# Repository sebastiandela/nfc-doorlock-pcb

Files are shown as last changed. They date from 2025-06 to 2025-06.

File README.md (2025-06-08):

# NFC-Controlled Electromagnetic Door Lock (Custom PCB)

The design files for a custom PCB created in Fusion 360 for an **NFC-controlled electromagnetic door lock**.

A **12V power supply** is used to power the eletromagnetic lock, NFC reader, and ATmega328P core. The schematic uses the Arduino Nano as the base and adds the additional functionality. 

## PCB Installation
This is an example of how the PCB can be used in a system.
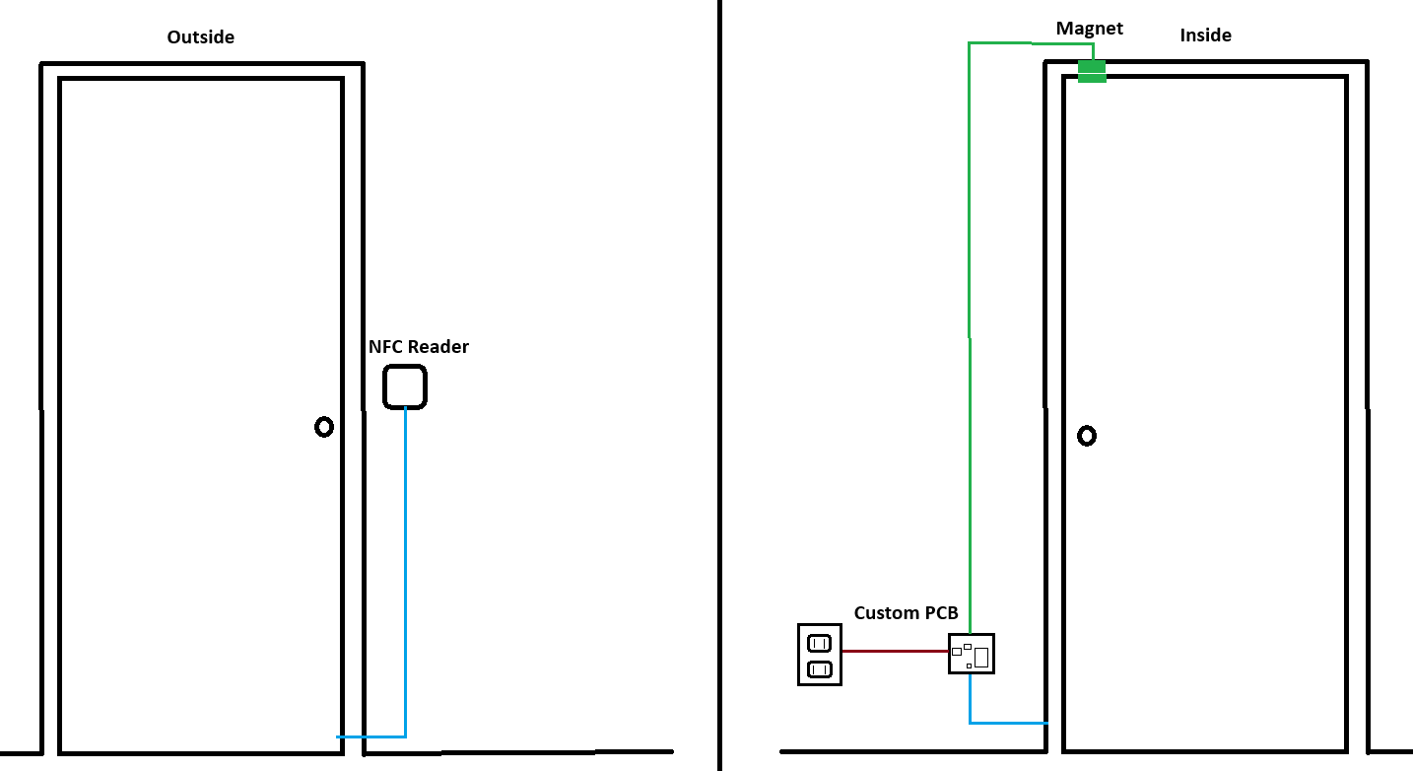
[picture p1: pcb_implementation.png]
Physical implementation of pcb


## Board Layout
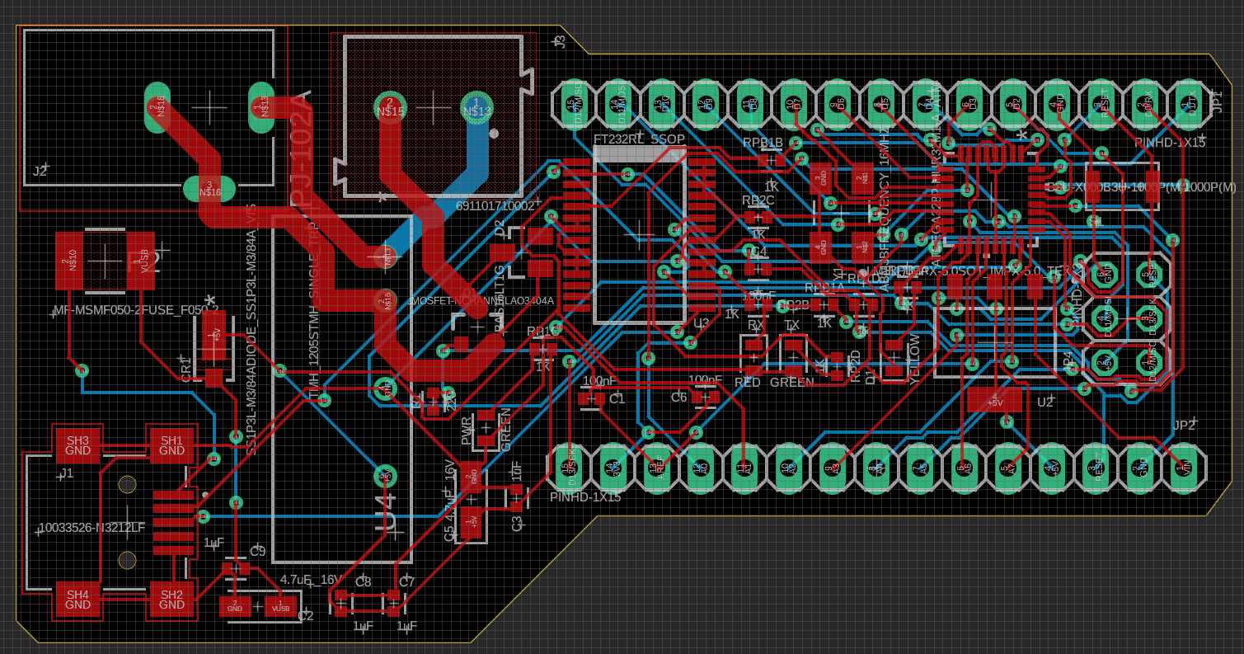
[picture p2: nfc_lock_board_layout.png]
Board layout


## 3D Model
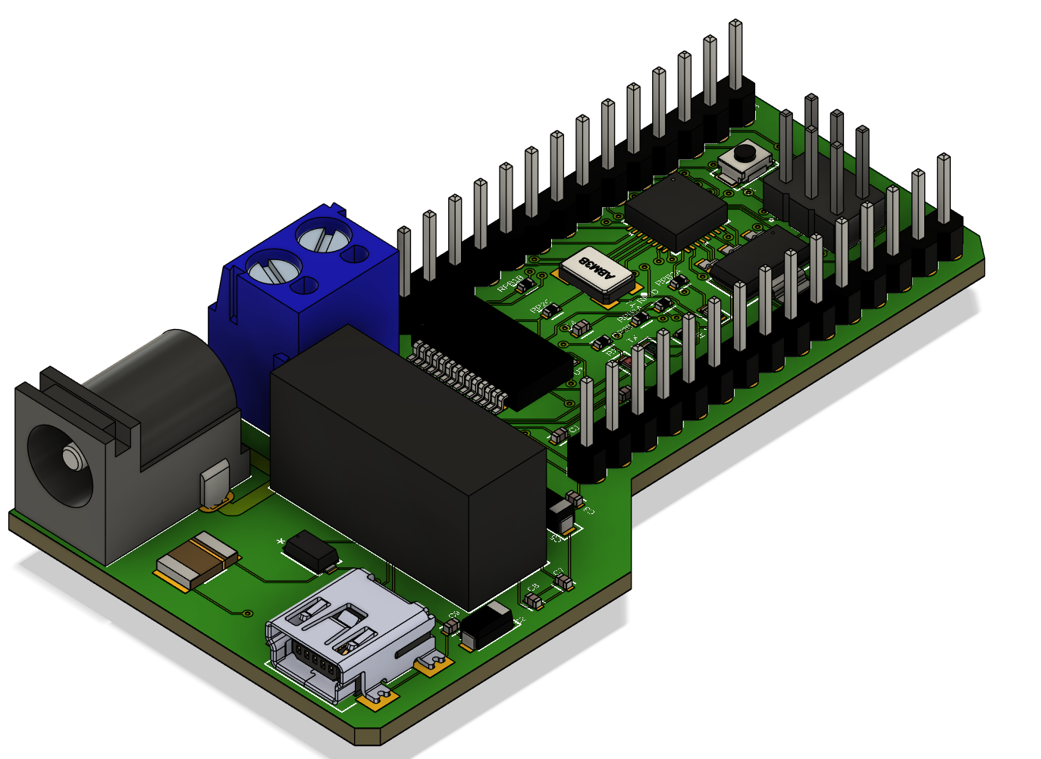
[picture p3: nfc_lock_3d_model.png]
PCB 3D model


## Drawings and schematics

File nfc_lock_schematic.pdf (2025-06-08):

## TMH_1205STMH_SINGLE_TRP

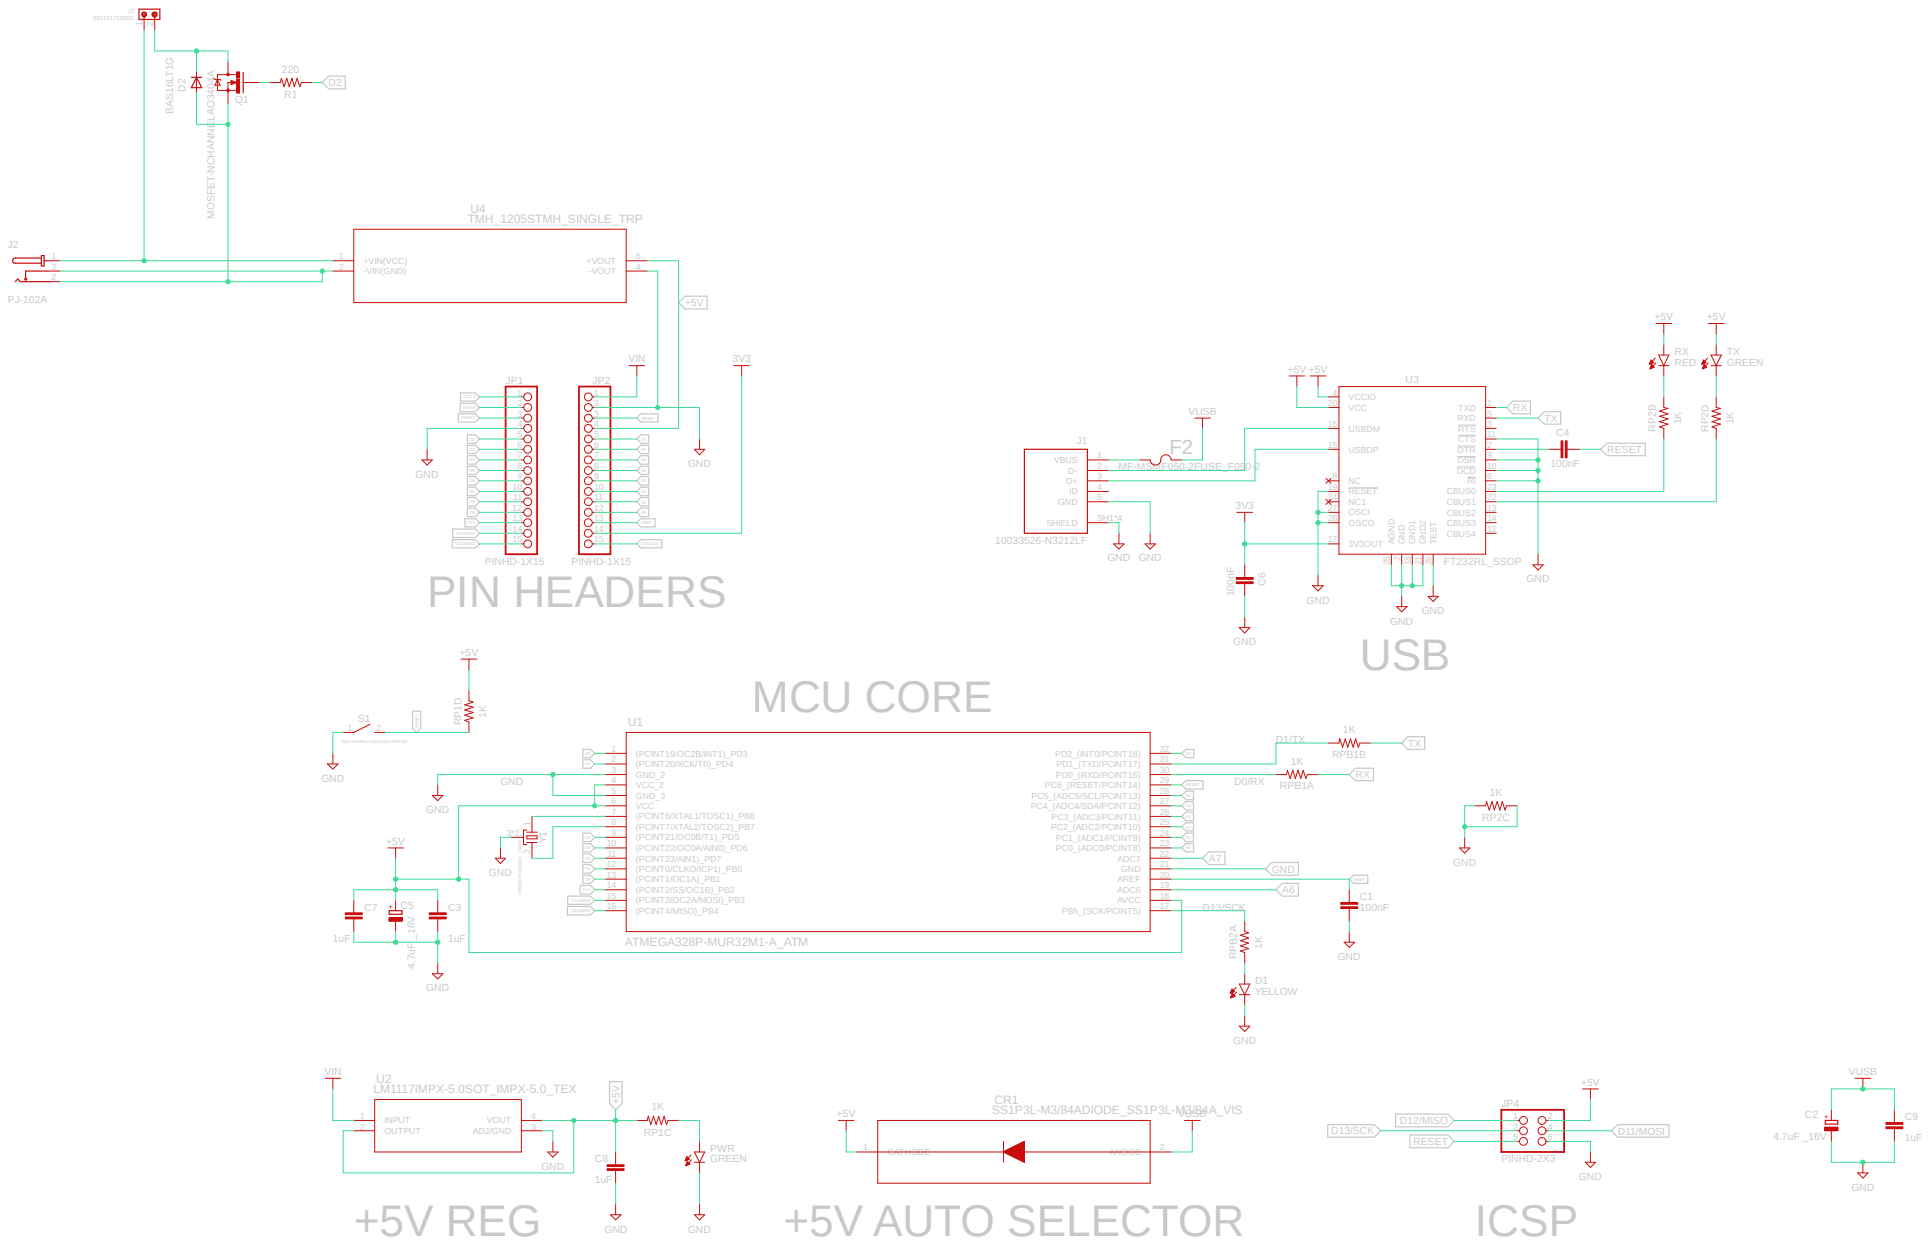
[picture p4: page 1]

7 GND1 18 GND2 21 TEST 26 CBUS4 12 CBUS3 14 CBUS2 13 CBUS1 22 CBUS0 23 RI 6 DCD 10 DSR 9 DTR 2 CTS 11 RTS 3 RXD 5 TXD 1 C4 RP2B RX RP2D

(PCINT2/SS/OC1B)_PB2 14 (PCINT3/OC2A/MOSI)_PB3 15 | A6

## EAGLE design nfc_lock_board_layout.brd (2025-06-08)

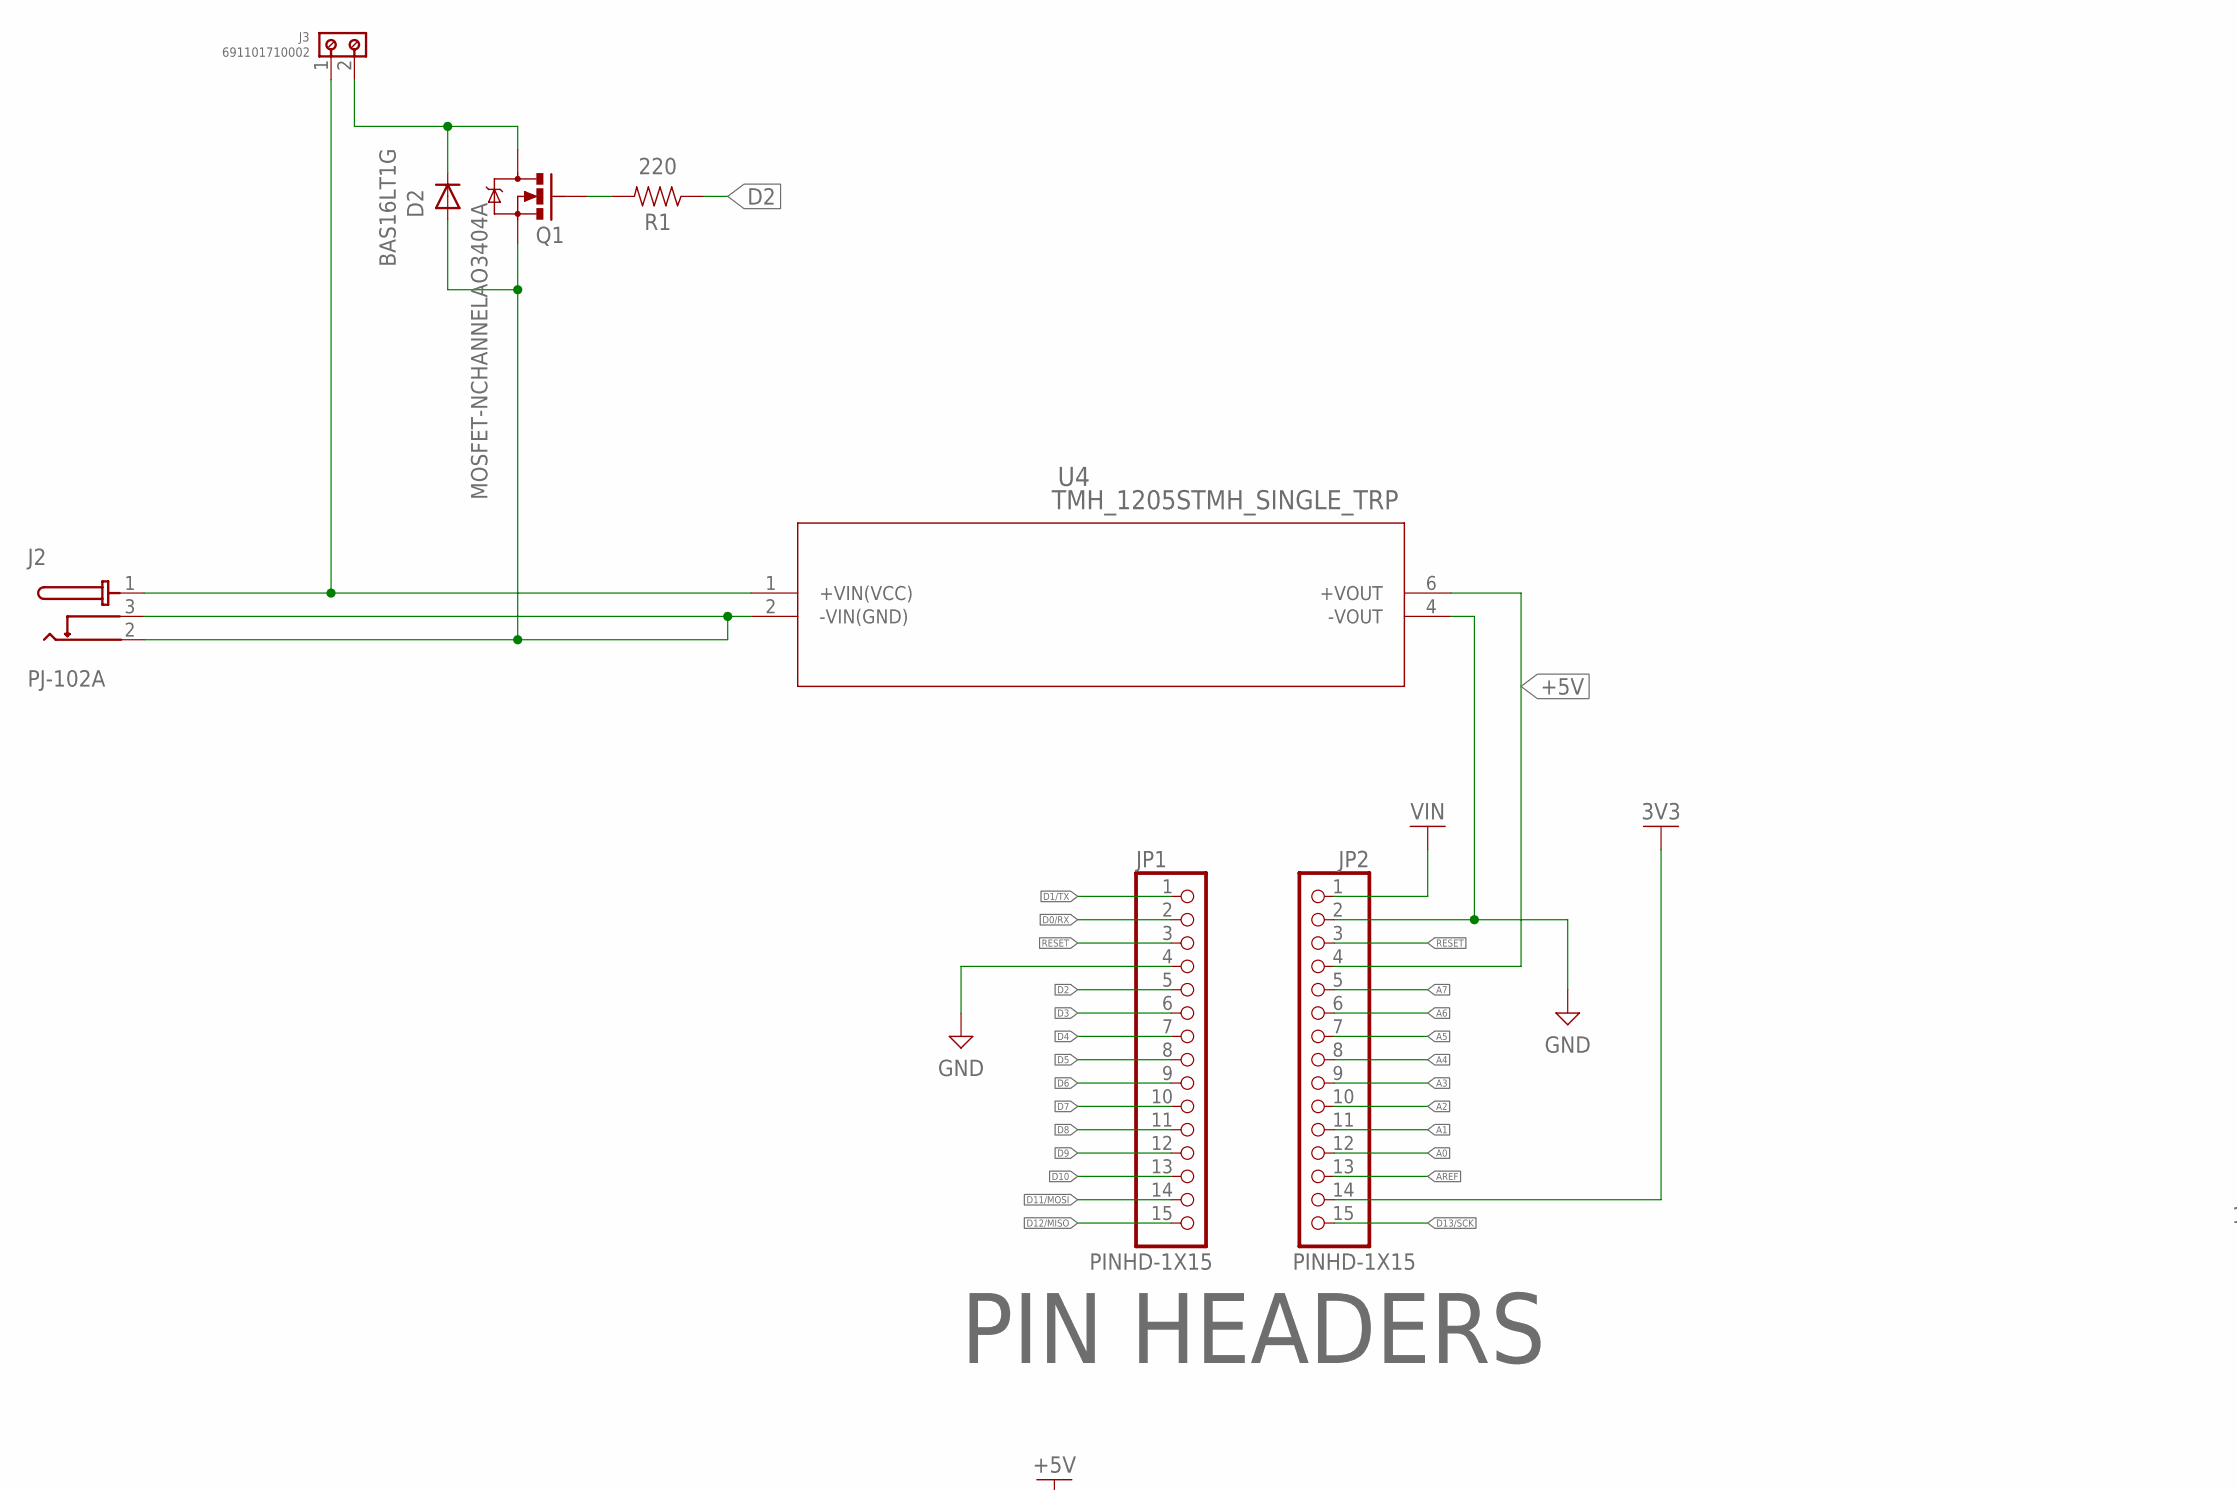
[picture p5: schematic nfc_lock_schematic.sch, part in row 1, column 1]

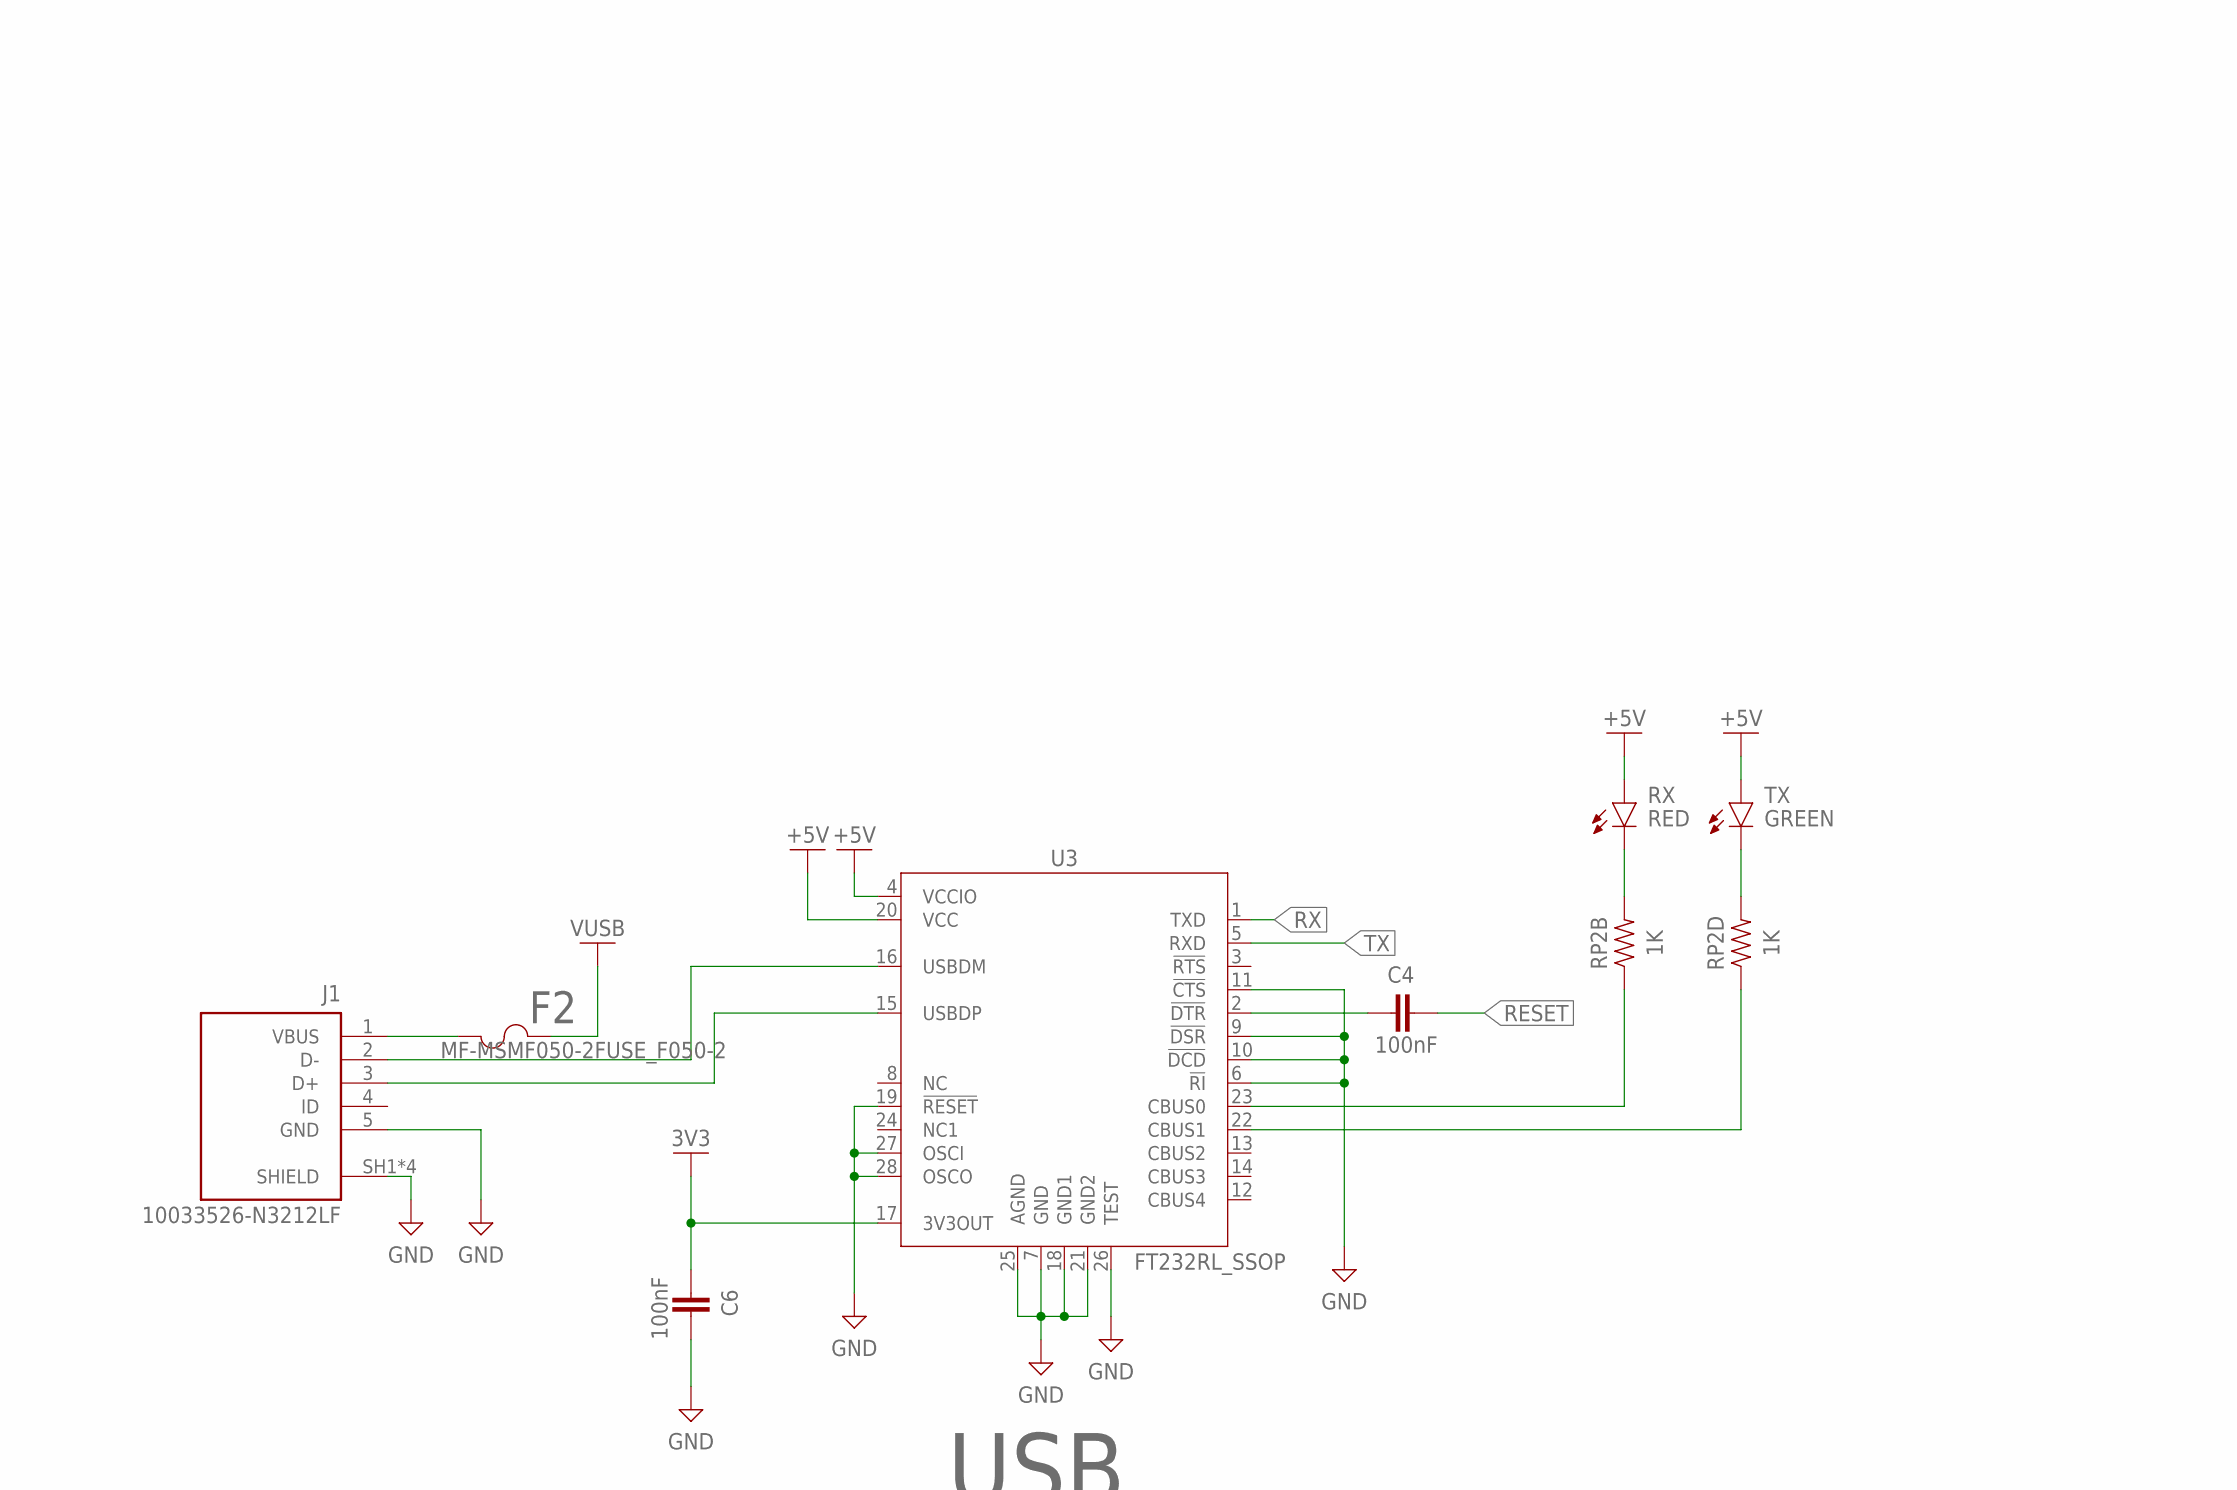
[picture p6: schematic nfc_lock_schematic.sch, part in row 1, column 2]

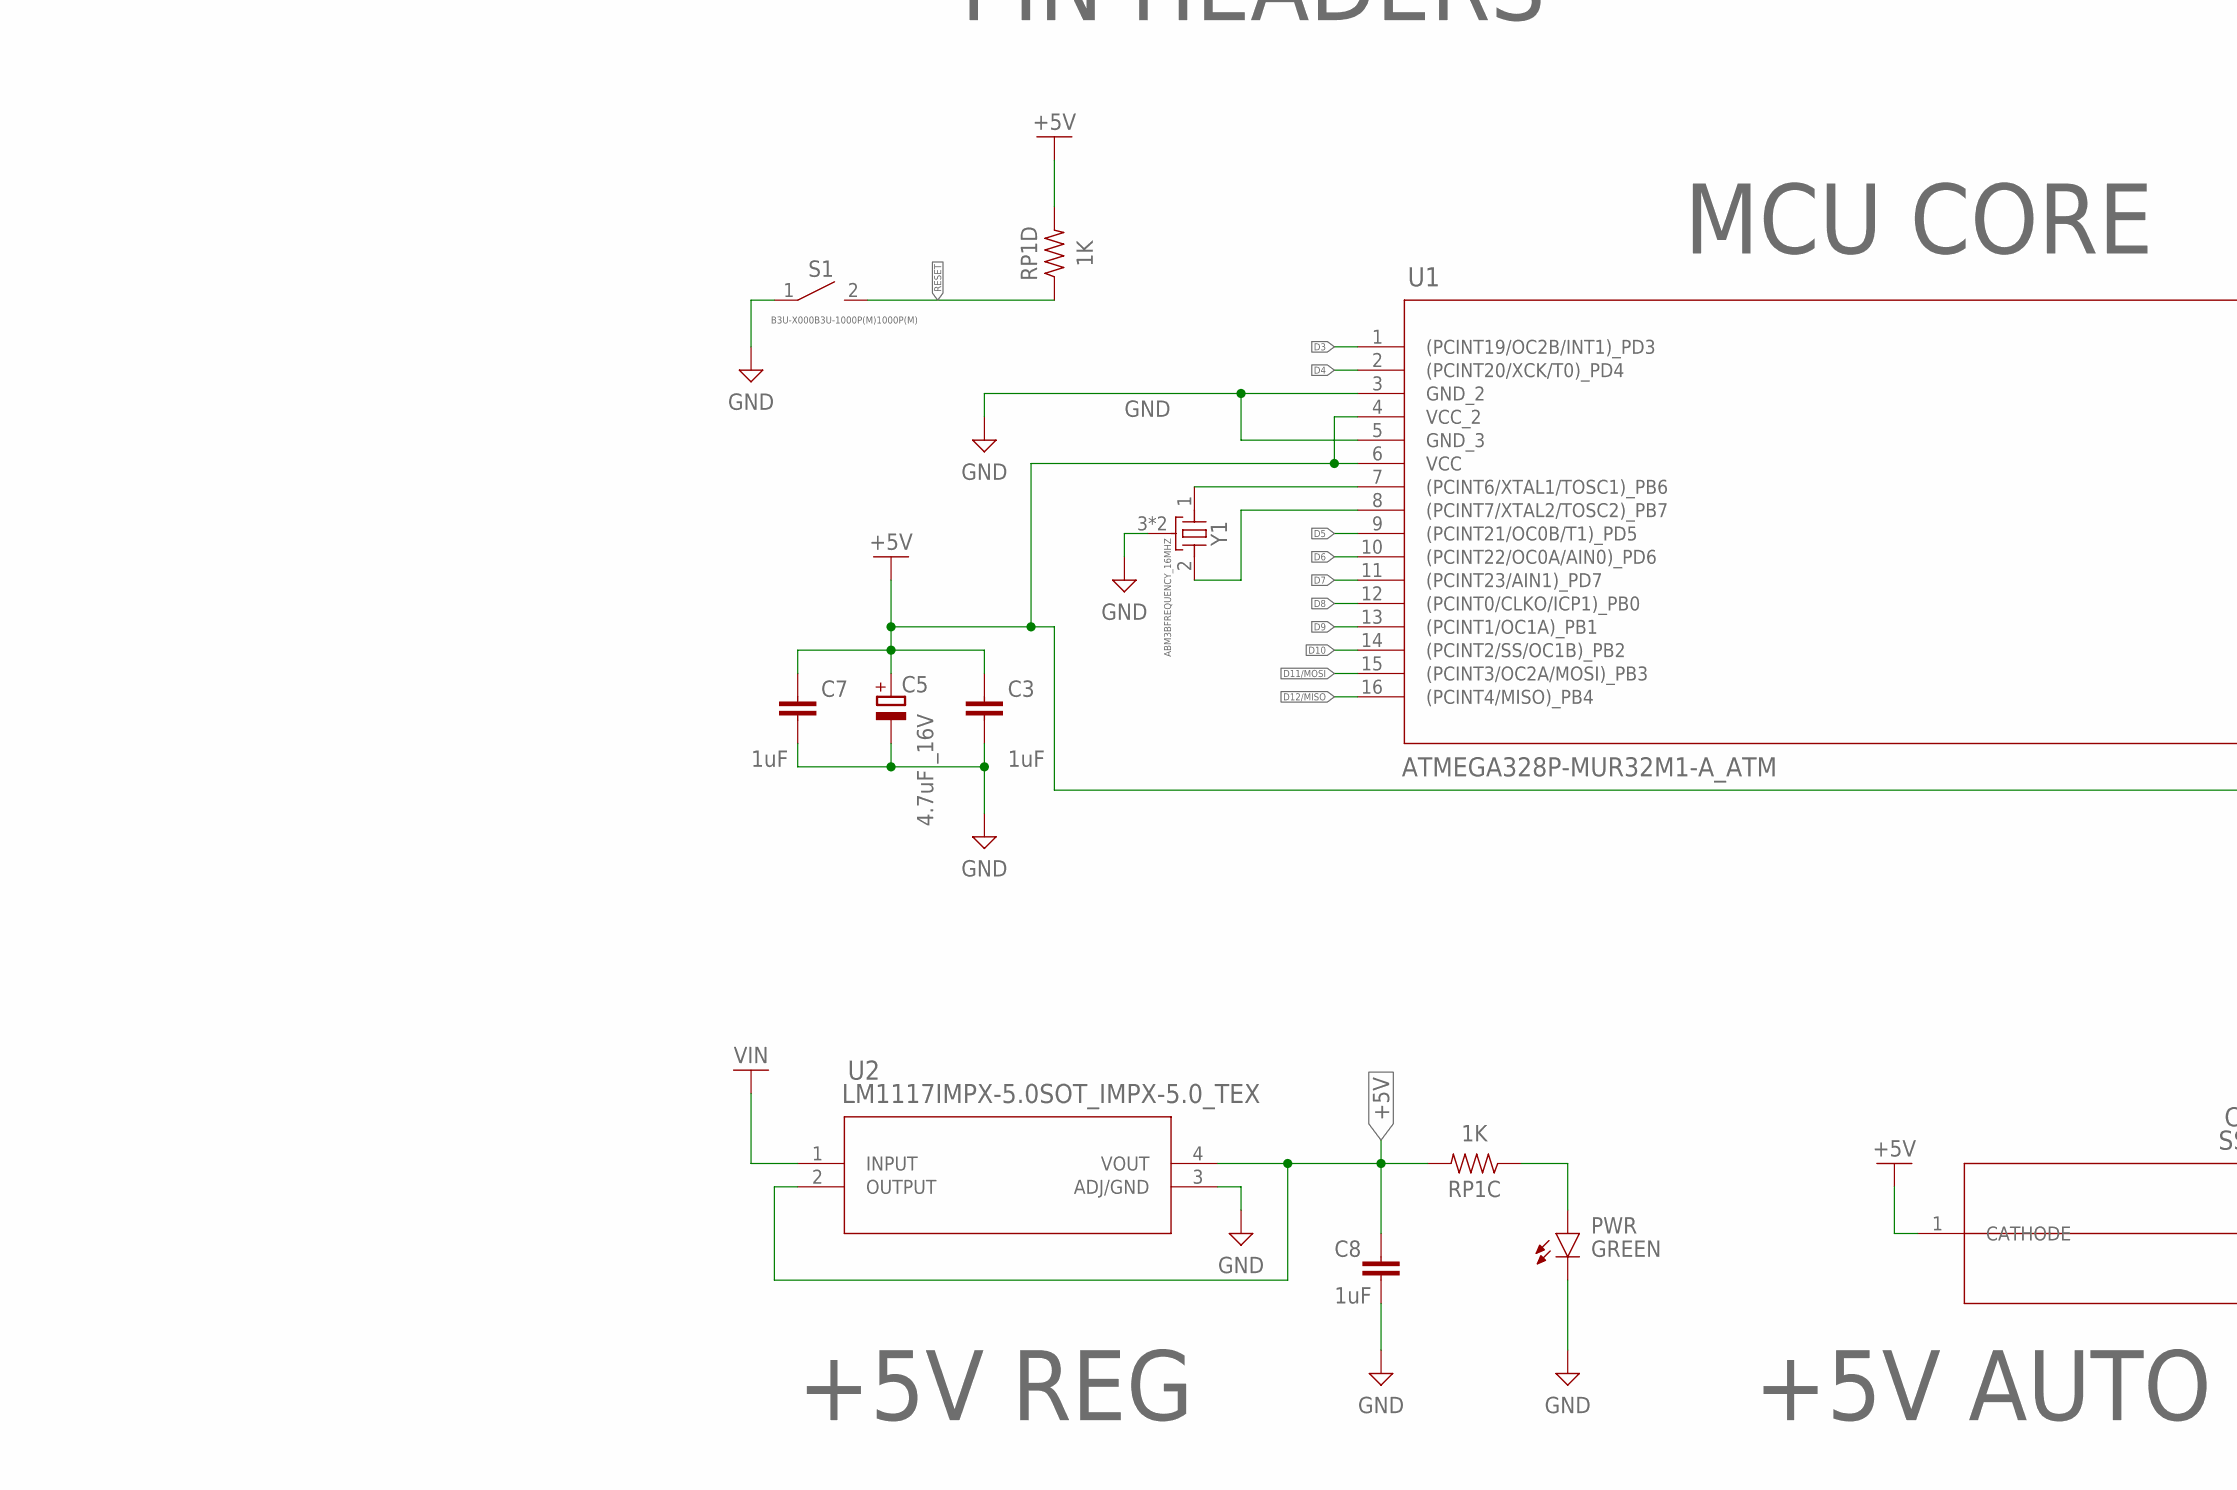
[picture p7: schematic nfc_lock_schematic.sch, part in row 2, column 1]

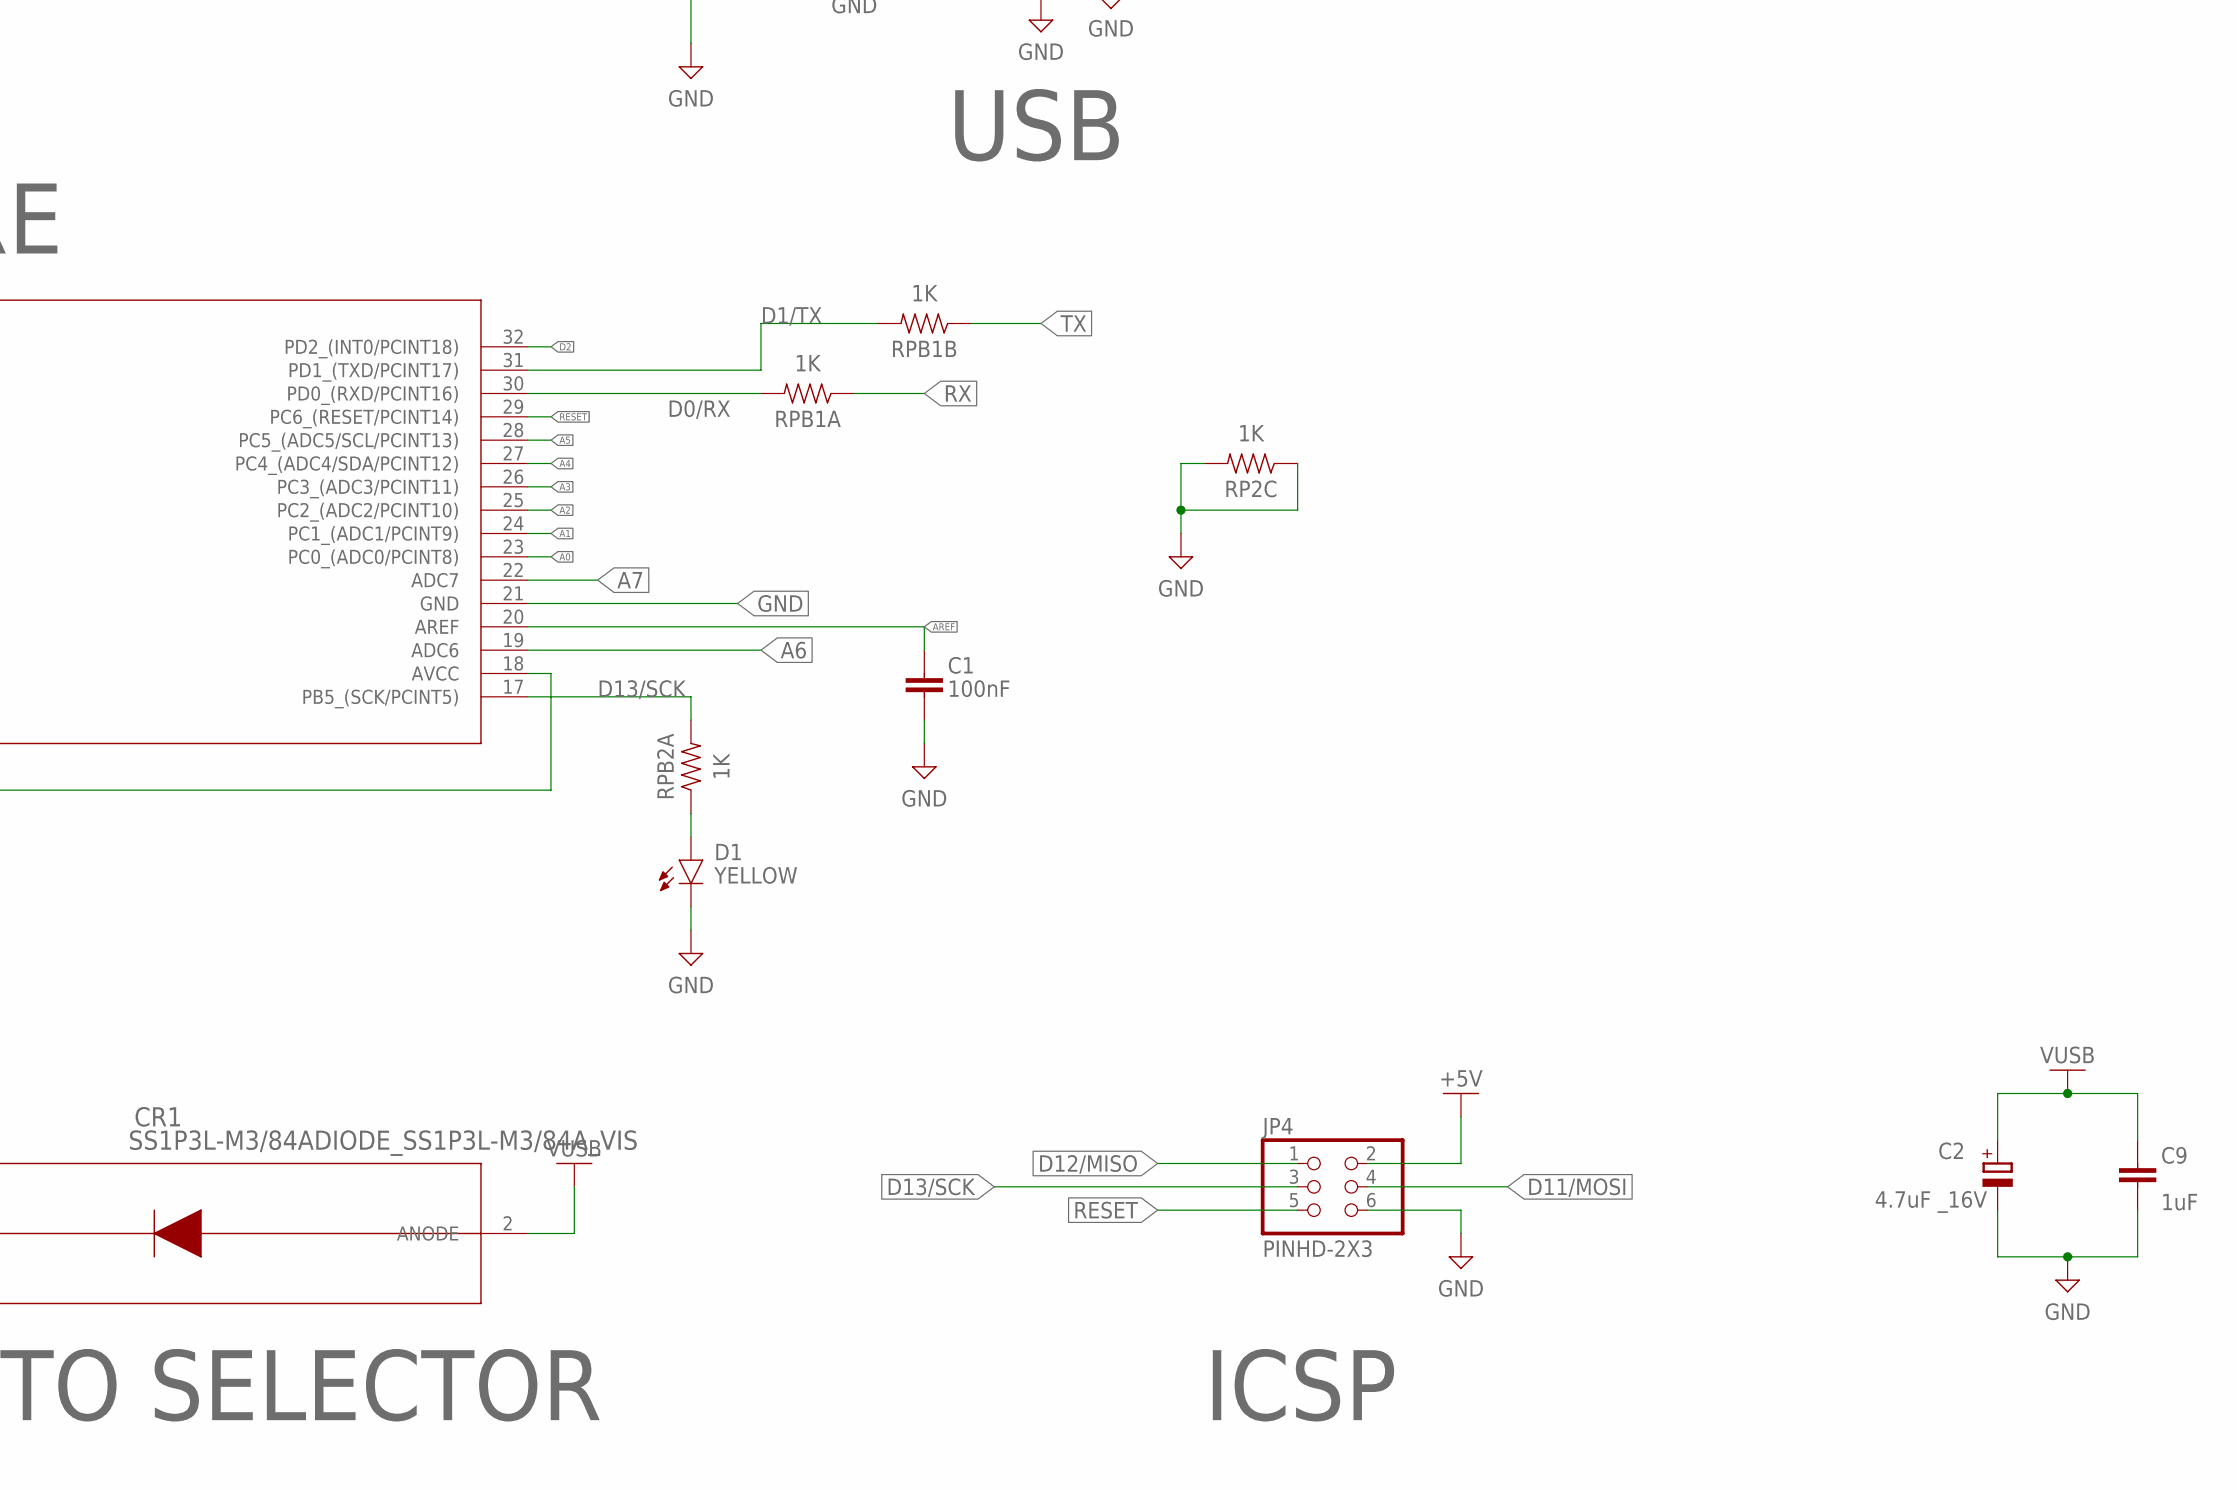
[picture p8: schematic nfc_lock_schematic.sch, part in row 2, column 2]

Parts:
C1, C4, C6: 100nF; CAPC1005X60
C2, C5: 4.7uF _16V; CAPMP3216X180N
C3, C7, C8, C9: 1uF; CAPC1005X60
CR1: SS1P3L-M3/84ADIODE_SS1P3L-M3/84A_VIS; DIODE_SS1P3L-M3/84A_VIS
D1: YELLOW; LEDC1608X35N_FLAT-Y
D2: BAS16LT1G; SOT23
F2: MF-MSMF050-2FUSE_F050-2; FUSE_F050-2
J1: 10033526-N3212LF; AMPHENOL_10033526-N3212LF
J2: PJ-102A; CUI_PJ-102A
J3: 691101710002
JP1, JP2: PINHD-1X15; 1X15
JP4: PINHD-2X3; 2X03
PWR: GREEN; LEDC1608X35N_FLAT-G
Q1: MOSFET-NCHANNELAO3404A; SOT23-3
R1: 220; RESC1005X40
RP1C, RP1D, RP2B, RP2C, RP2D: 1K; RESC1005X40
RPB1A, RPB1B, RPB2A: 1K; RESC1005X40
RX: RED; LEDC1608X35N_FLAT-R
S1: B3U-X000B3U-1000P(M)1000P(M); B3U-1000P(M)
TX: GREEN; LEDC1608X35N_FLAT-G
U1: ATMEGA328P-MUR32M1-A_ATM; 32M1-A_ATM
U2: LM1117IMPX-5.0SOT_IMPX-5.0_TEX; SOT_IMPX-5.0_TEX
U3: FT232RL_SSOP; SSOP28
U4: TMH_1205STMH_SINGLE_TRP; TMH_SINGLE_TRP
Y1: ABM3BFREQUENCY_16MHZ; OSCSC500X320X110-4N

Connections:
3V3: C6.1, JP2.14, U3.17 (3V3OUT)
+5V: C3.1, C5.1 (+), C7.1, C8.1, CR1.1 (CATHODE), JP2.4, JP4.2, RP1C.2, RP1D.2, RX.A, TX.A, U1.4 (VCC_2), U1.6 (VCC), U1.18 (AVCC), U2.2 (OUTPUT), U2.4 (VOUT), U3.4 (VCCIO), U3.20 (VCC), U4.6 (+VOUT)
A0: JP2.12, U1.23 (PC0_(ADC0/PCINT8))
A1: JP2.11, U1.24 (PC1_(ADC1/PCINT9))
A2: JP2.10, U1.25 (PC2_(ADC2/PCINT10))
A3: JP2.9, U1.26 (PC3_(ADC3/PCINT11))
A4: JP2.8, U1.27 (PC4_(ADC4/SDA/PCINT12))
A5: JP2.7, U1.28 (PC5_(ADC5/SCL/PCINT13))
A6: JP2.6, U1.19 (ADC6)
A7: JP2.5, U1.22 (ADC7)
AREF: C1.1, JP2.13, U1.20 (AREF)
D0/RX: JP1.2, RPB1A.2, U1.30 (PD0_(RXD/PCINT16))
D1/TX: JP1.1, RPB1B.2, U1.31 (PD1_(TXD/PCINT17))
D2: JP1.5, Q1.1 (G), R1.1, R1.2, U1.32 (PD2_(INT0/PCINT18))
D3: JP1.6, U1.1 ((PCINT19/OC2B/INT1)_PD3)
D4: JP1.7, U1.2 ((PCINT20/XCK/T0)_PD4)
D5: JP1.8, U1.9 ((PCINT21/OC0B/T1)_PD5)
D6: JP1.9, U1.10 ((PCINT22/OC0A/AIN0)_PD6)
D7: JP1.10, U1.11 ((PCINT23/AIN1)_PD7)
D8: JP1.11, U1.12 ((PCINT0/CLKO/ICP1)_PB0)
D9: JP1.12, U1.13 ((PCINT1/OC1A)_PB1)
D10: JP1.13, U1.14 ((PCINT2/SS/OC1B)_PB2)
D11/MOSI: JP1.14, JP4.4, U1.15 ((PCINT3/OC2A/MOSI)_PB3)
D12/MISO: JP1.15, JP4.1, U1.16 ((PCINT4/MISO)_PB4)
D13/SCK: JP2.15, JP4.3, RPB2A.2, U1.17 (PB5_(SCK/PCINT5))
GND: C1.2, C2.2 (-), C3.2, C5.2 (-), C6.2, C7.2, C8.2, C9.2, D1.C, J1.5 (GND), J1.SH1 (SHIELD), J1.SH2 (SHIELD), J1.SH3 (SHIELD), J1.SH4 (SHIELD), JP1.4, JP2.2, JP4.6, PWR.C, RP2C.1, RP2C.2, S1.1, U1.3 (GND_2), U1.5 (GND_3), U1.21 (GND), U2.3 (ADJ/GND), U3.6 (!RI), U3.7 (GND), U3.9 (!DSR), U3.10 (!DCD), U3.11 (!CTS), U3.18 (GND1), U3.19 (!RESET), U3.21 (GND2), U3.25 (AGND), U3.26 (TEST), U3.27 (OSCI), U3.28 (OSCO), U4.4 (-VOUT), Y1.3 (GND), Y1.4 (GND)
unnamed: U1.8 ((PCINT7/XTAL2/TOSC2)_PB7), Y1.2
unnamed: U1.7 ((PCINT6/XTAL1/TOSC1)_PB6), Y1.1
unnamed: PWR.A, RP1C.1
unnamed: D1.A, RPB2A.1
unnamed: C4.1, U3.2 (!DTR)
unnamed: RP2B.1, U3.23 (CBUS0)
unnamed: RP2B.2, RX.C
unnamed: RP2D.1, U3.22 (CBUS1)
unnamed: RP2D.2, TX.C
unnamed: F2.2, J1.1 (VBUS)
unnamed: J1.2 (D-), U3.16 (USBDM)
unnamed: J1.3 (D+), U3.15 (USBDP)
unnamed: J2.1, J3.1, U4.1 (+VIN(VCC))
unnamed: D2.3 (K), J3.2, Q1.3 (D)
unnamed: D2.1 (A), J2.2, J2.3, Q1.2 (S), U4.2 (-VIN(GND))
RESET: C4.2, JP1.3, JP2.3, JP4.5, RP1D.1, S1.2, U1.29 (PC6_(RESET/PCINT14))
RX: RPB1A.1, U3.1 (TXD)
TX: RPB1B.1, U3.5 (RXD)
VIN: JP2.1, U2.1 (INPUT)
VUSB: C2.1 (+), C9.1, CR1.2 (ANODE), F2.1

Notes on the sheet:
MCU CORE
+5V REG
+5V AUTO SELECTOR
ICSP
PIN HEADERS
USB

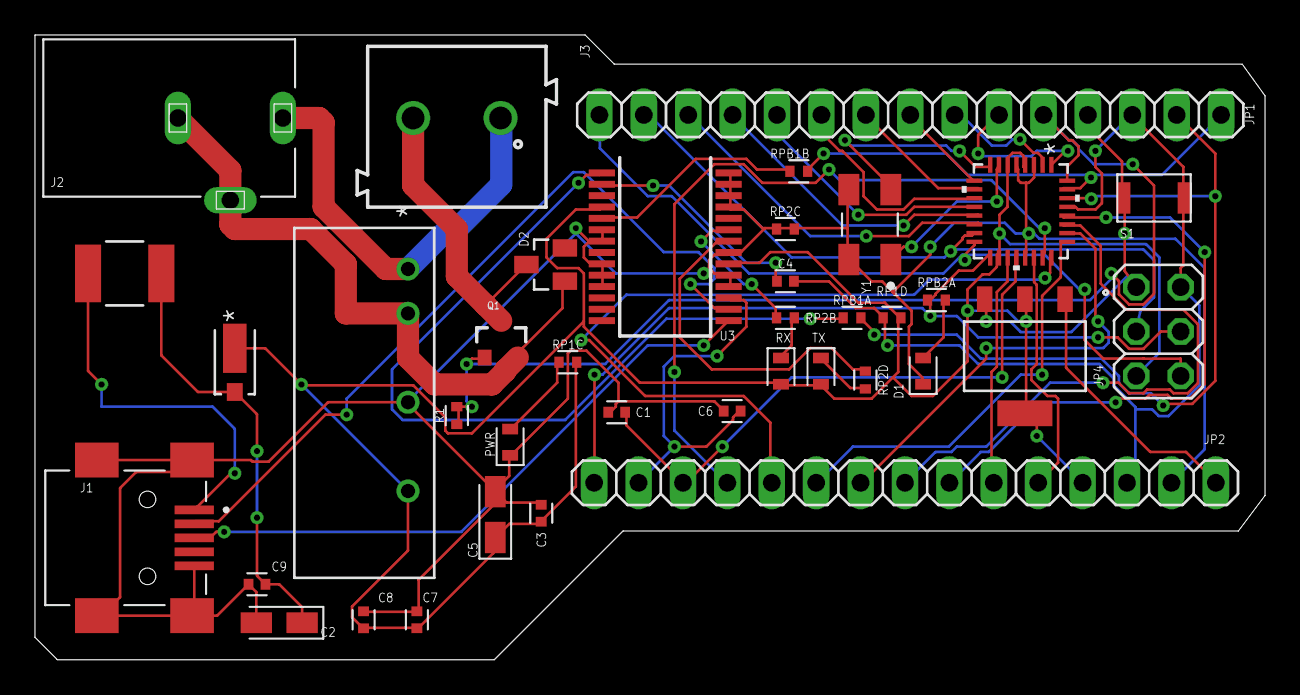
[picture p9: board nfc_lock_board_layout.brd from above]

Board: 2 copper layers, 70.4 x 35.7 mm, 38 parts (0 on the bottom side), 46 nets.

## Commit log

2025-06-08 Upload pcb files
    [nfc_lock_board_layout.brd, nfc_lock_schematic.sch]
2025-06-08 Add pcb implementation diagram

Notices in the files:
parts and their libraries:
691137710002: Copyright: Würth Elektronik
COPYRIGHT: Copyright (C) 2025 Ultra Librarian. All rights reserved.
